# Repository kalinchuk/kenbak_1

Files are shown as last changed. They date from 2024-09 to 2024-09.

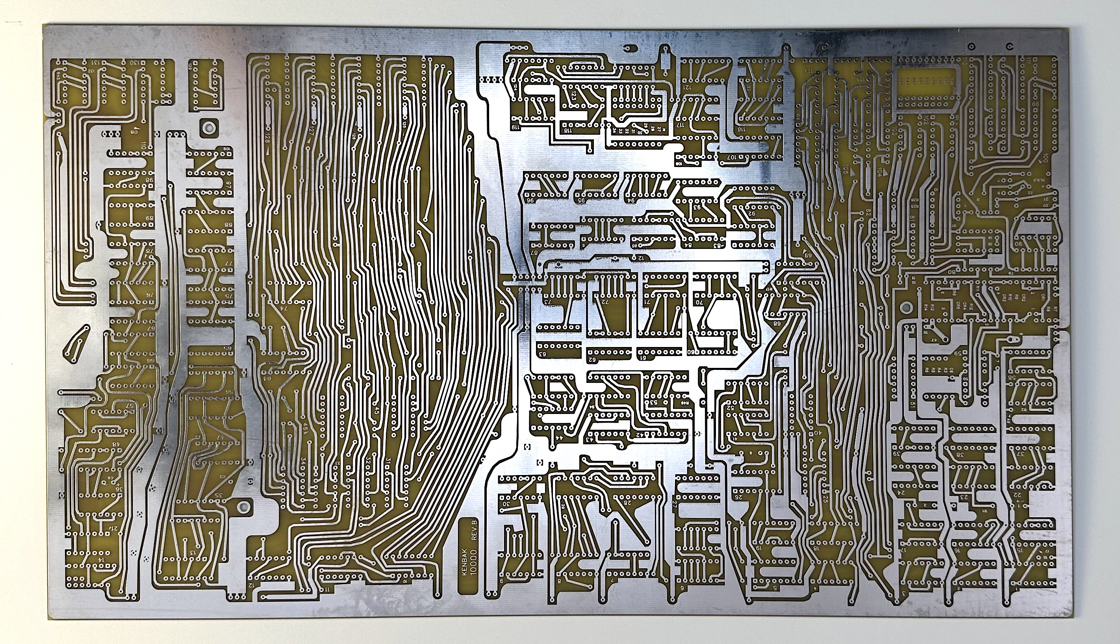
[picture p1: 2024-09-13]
PCB.jpeg

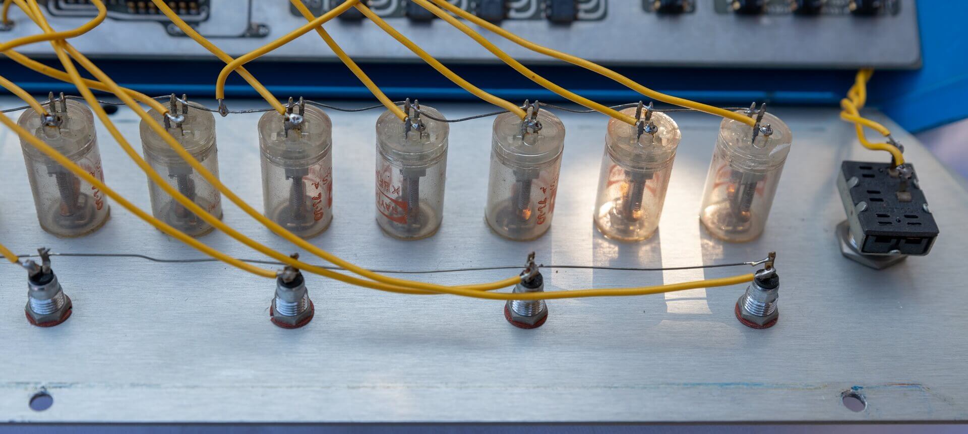
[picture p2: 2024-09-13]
Switches.jpg

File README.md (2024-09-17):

# Kenbak-1 Reproduction

This repository contains schematics, PCBs, instructions and parts lists for the Kenbak-1 reproduction build which can be found at [https://www.youtube.com/watch?v=ffsnZ321Xv4](https://www.youtube.com/watch?v=ffsnZ321Xv4). Be sure to check out [www.kenbak.com](https://www.kenbak.com) for much more details on the Kenbak-1 and its operation. [www.kenbakkit.com](http://www.kenbakkit.com/) also has a lot of resources pertaining to building the reproduction Kenbak-1.

Kenbak-1 Computer

## Resources

You will find the parts list, parts layout, literature (i.e. Theory of Operation), etc. in the tree of this repo.

The parts list and placement can be found [here](Literature/KENBAK-Parts%20Placement%20Guide-Release1.pdf).

Other construction details can be found [here](Literature/KENBAK-Stockly%20Electronics%20Construction%20Manual-Release1.pdf).

## Main PCB

The original Kenbak-1 PCBs are pretty much non-existent. Therefore, if one has the desire to build a Kenbak-1 computer, they need to use a reproduction PCB. I believe it was Thomas Jones who created a reproduction PCB for the Kenbak-1. I used his copper layers to create the Gerber file (included in this repo). I then got the PCBs fabricated and made them available for sale at [www.kalinchuk.com](https://www.kalinchuk.com/product-page/kenbak-1-reproduction-pcb) for anyone wanting to build their own Kenbak-1 computer.

Kenbak-1 PCB

Kenbak-1 Assembled PCB

## Power Supply

The power supply used in the videos and included with the kit: https://www.digikey.com/en/products/detail/integrated-power-designs/1010417CHCO/12757784

## Case

The reproduction Kenbak-1 case was designed by Chris Davis and was based on the original case by Bud Industries. You can find more details on the construction of it at [https://www.pcbway.com/project/shareproject/KENBAK_1_Case_652ebb23.html](https://www.pcbway.com/project/shareproject/KENBAK_1_Case_652ebb23.html).

Kenbak-1 Case

Kenbak-1 Case

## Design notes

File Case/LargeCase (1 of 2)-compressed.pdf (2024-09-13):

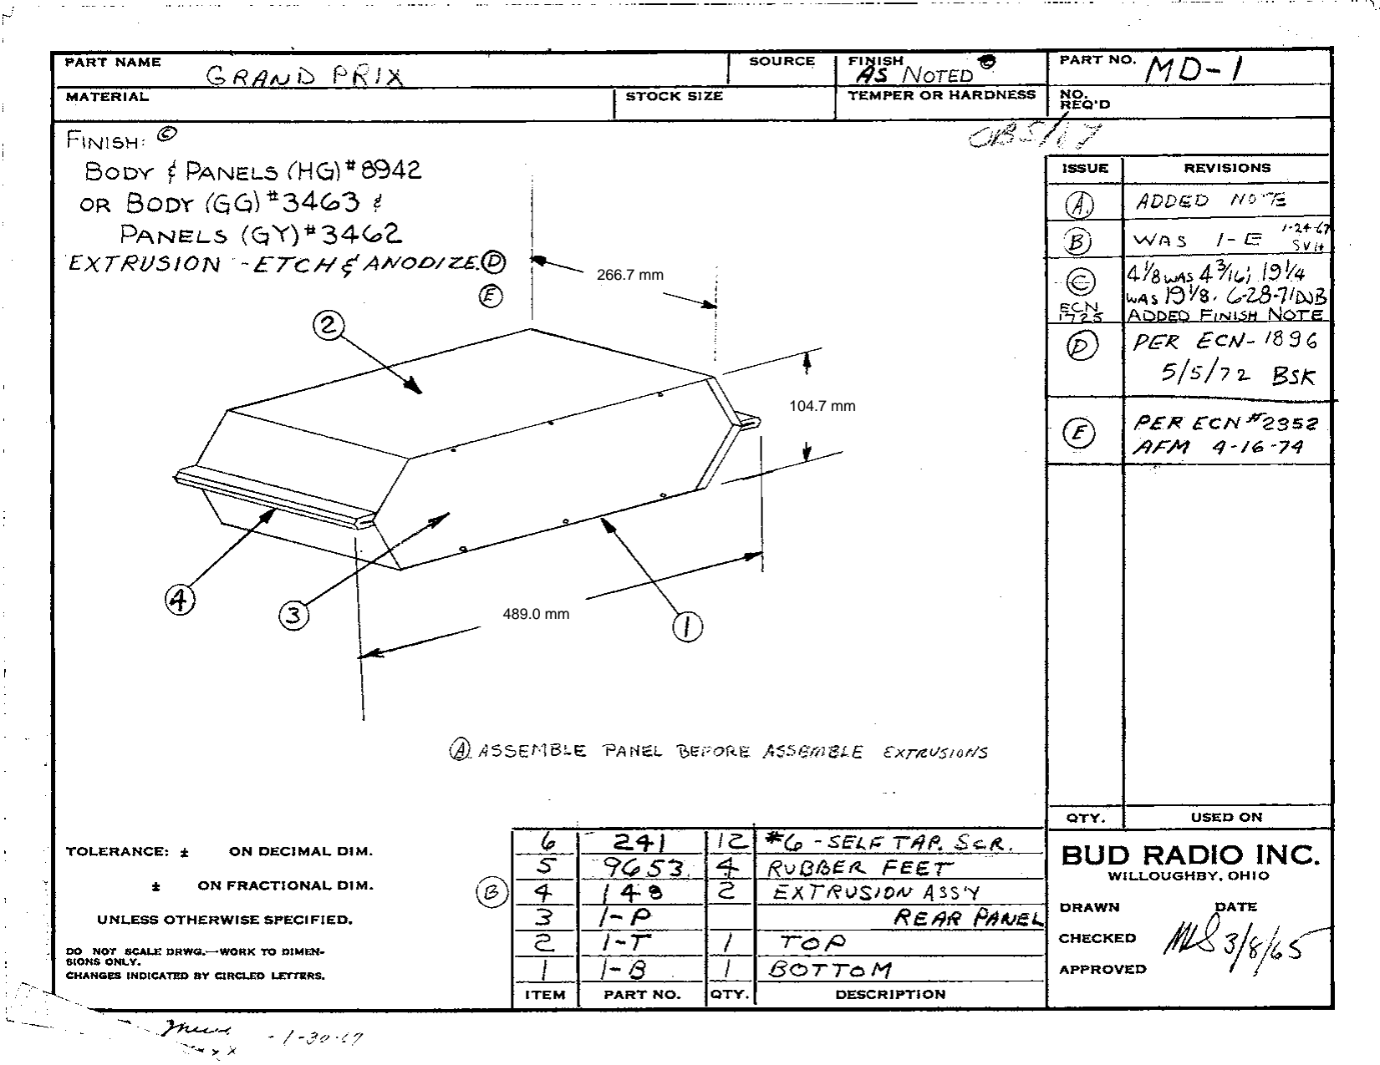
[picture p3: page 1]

266.7 mm

104.7 mm

489.0 mm

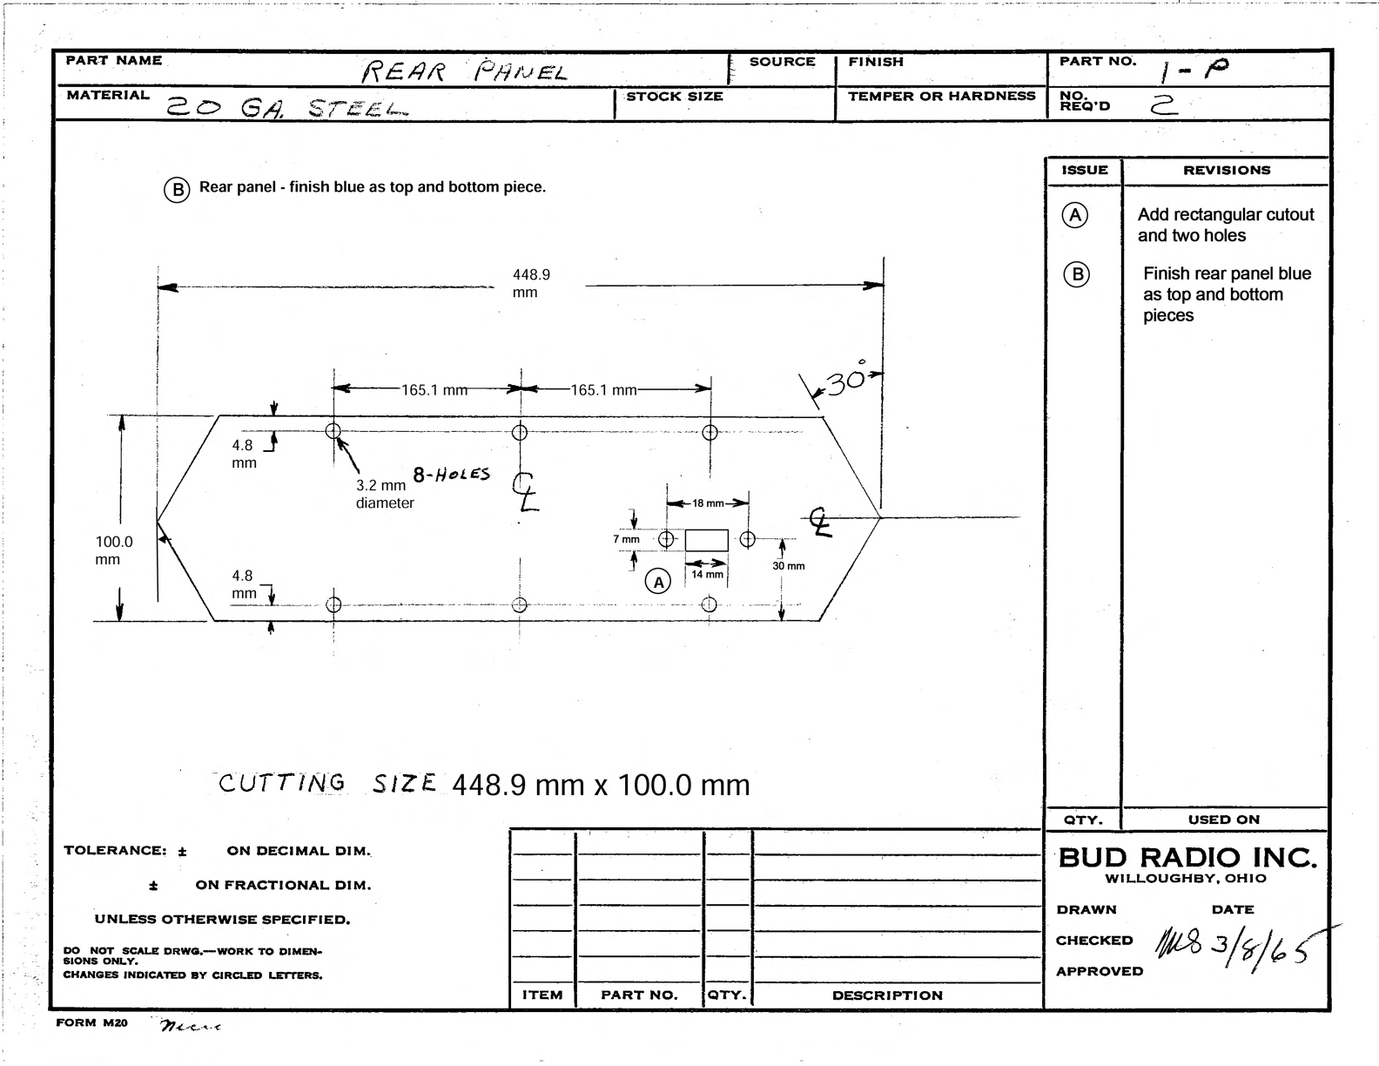
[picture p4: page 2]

## Top and Bottom - 2 pieces

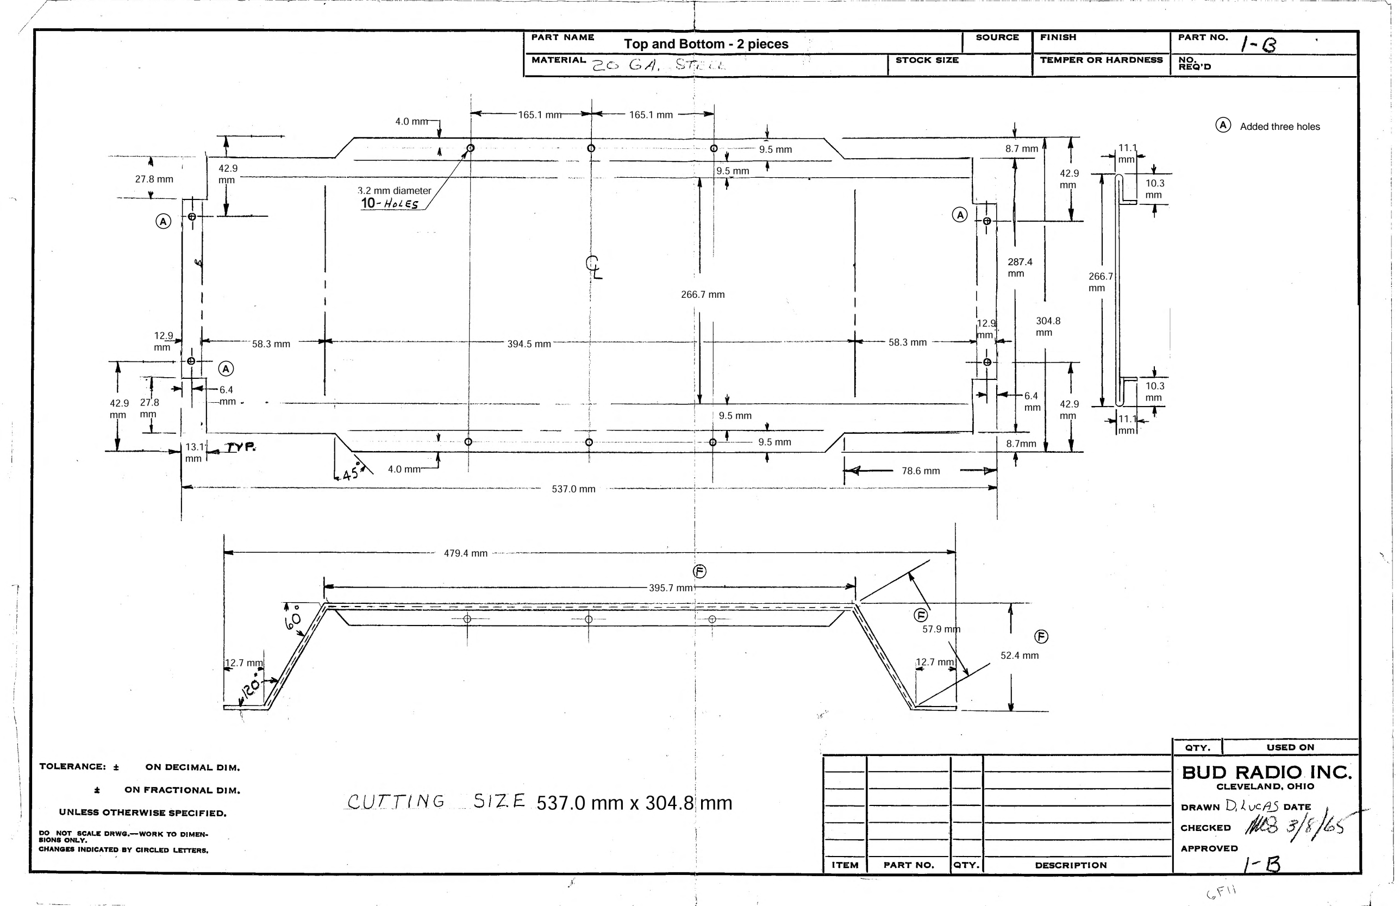
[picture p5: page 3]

A

A

A

A Added three holes

287.4
mm

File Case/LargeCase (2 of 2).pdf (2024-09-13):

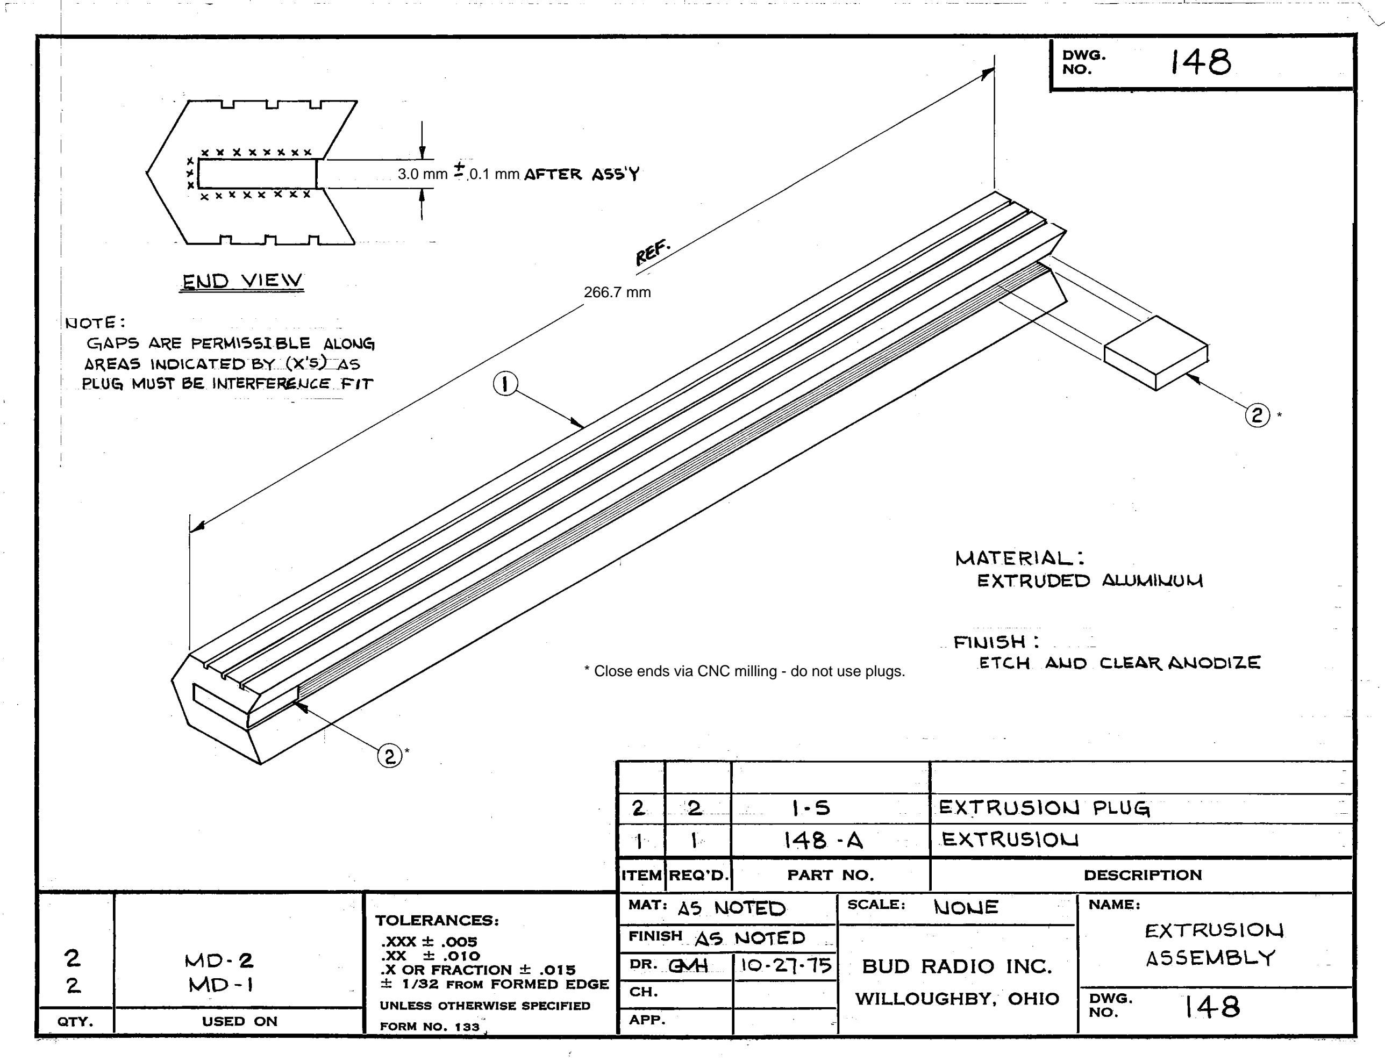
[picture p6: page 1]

3.0 mm 0.1 mm

266.7 mm

## M3 hex

* Close ends via CNC milling - do not use plugs.

*

*

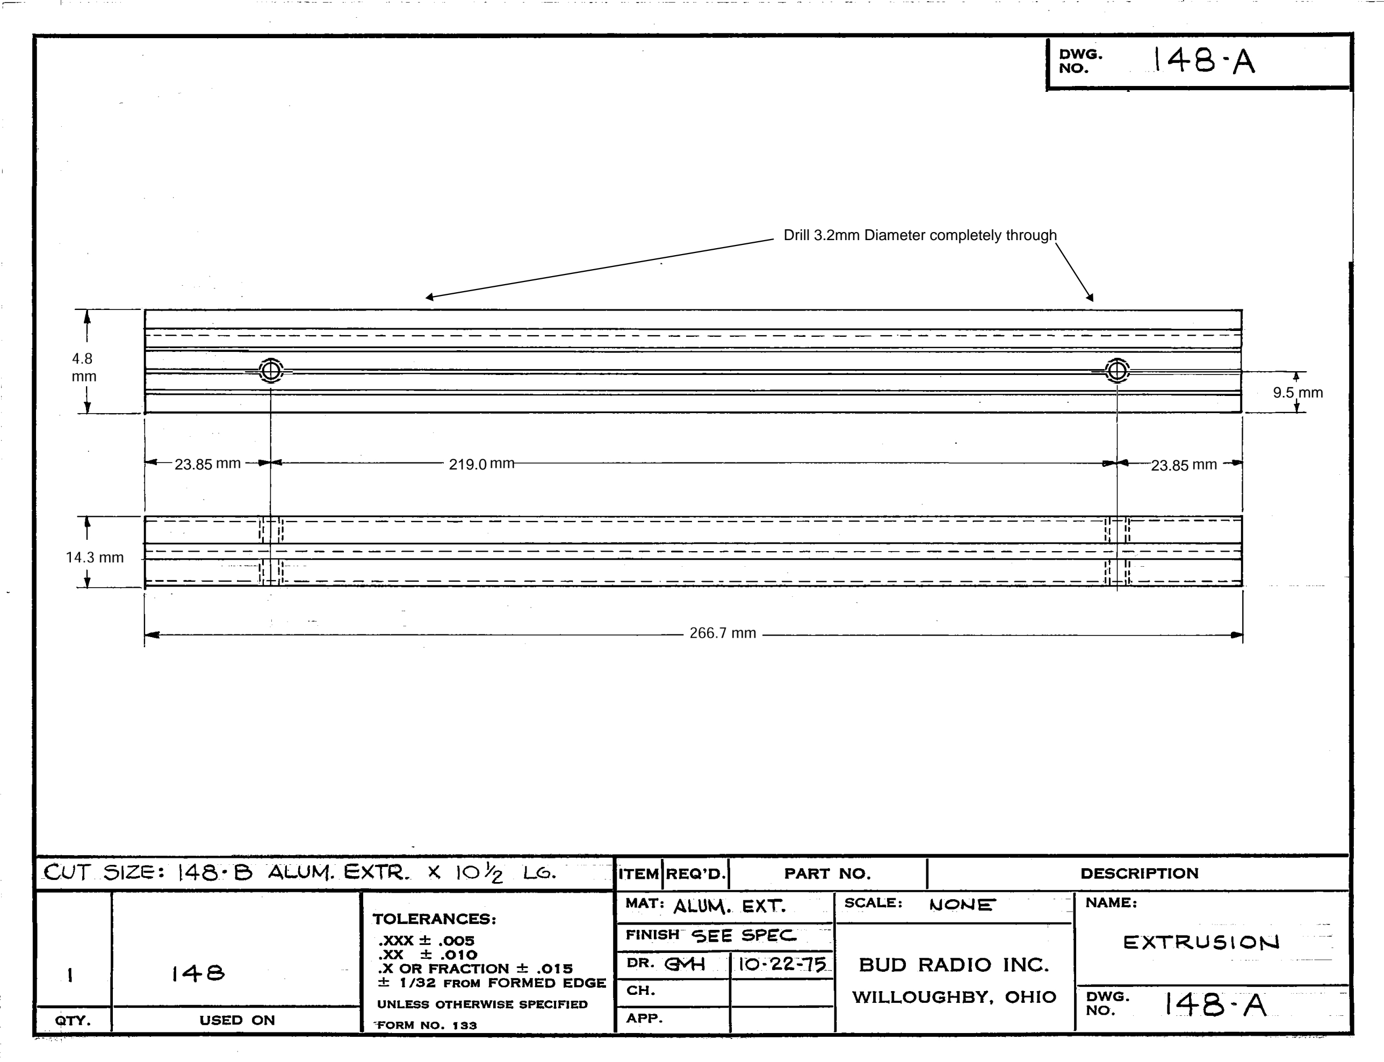
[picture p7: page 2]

Drill 3.2mm Diameter completely through

9.5 mm

23.85 | 219.0 | 23.85

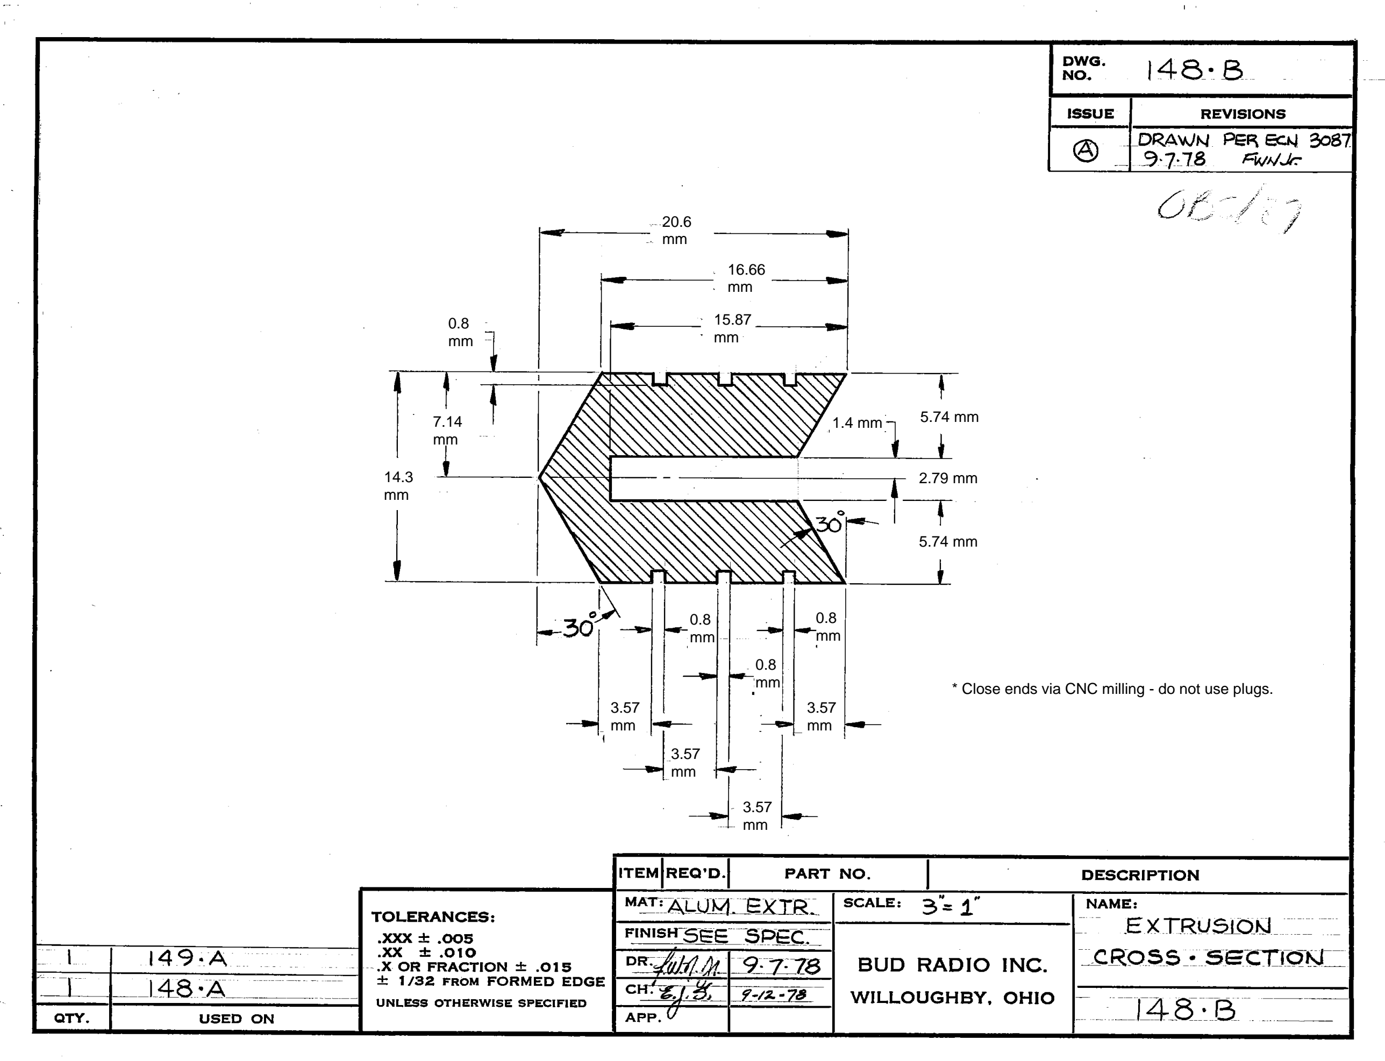
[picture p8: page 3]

14.3
mm

7.14
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
3.57
mm
3.57
mm

3.57
mm

3.57
mm

20.6
mm
16.66
mm

15.87
mm

5.74 mm

5.74 mm

2.79 mm

1.4 mm

* Close ends via CNC milling - do not use plugs.

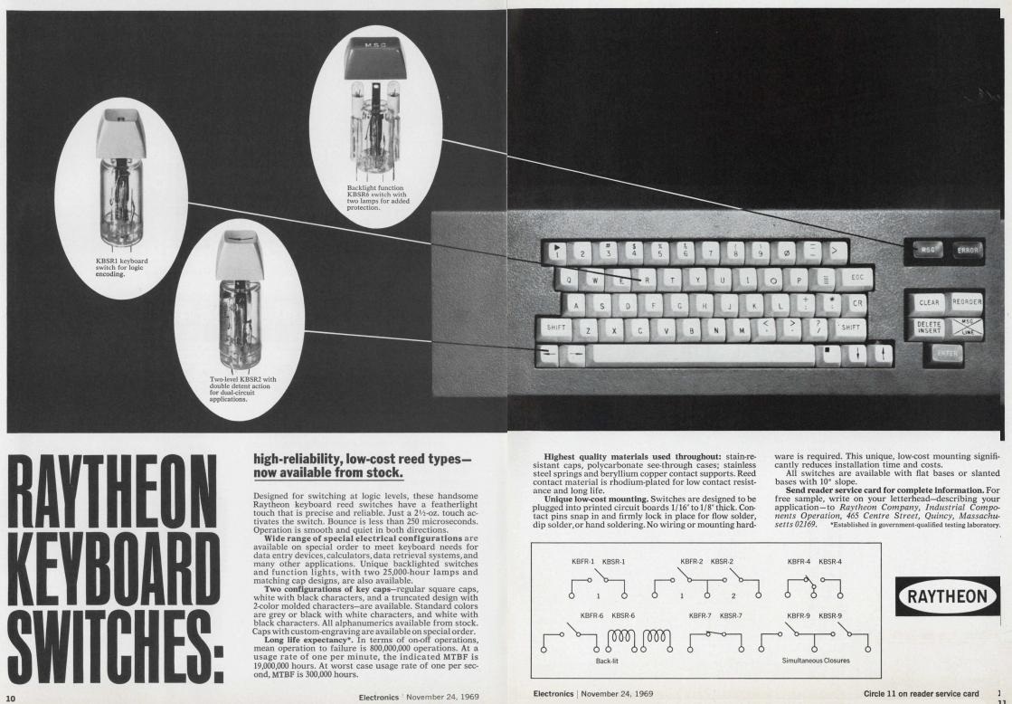
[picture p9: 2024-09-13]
raytheonkeyswitches.png

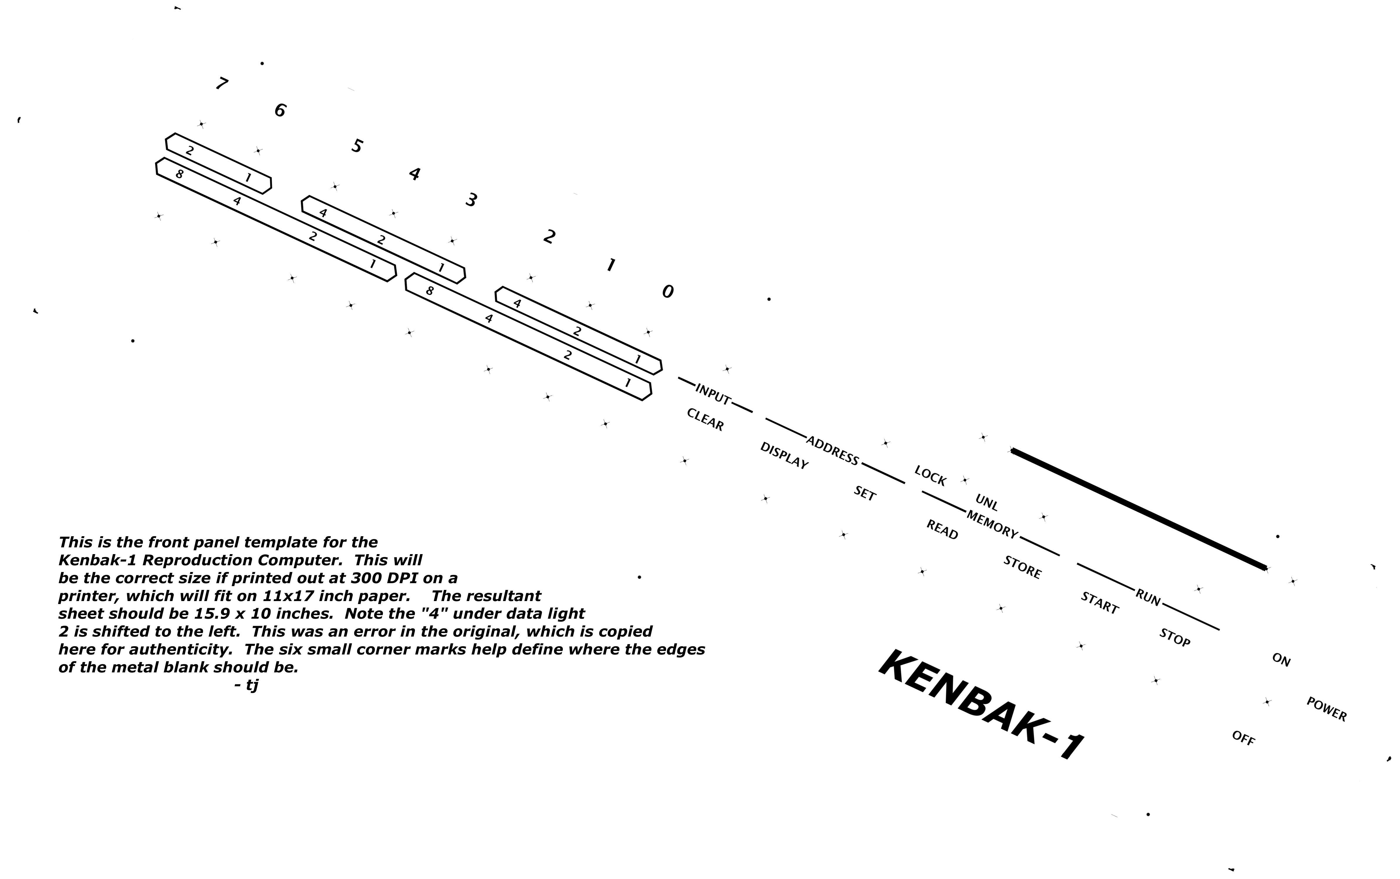
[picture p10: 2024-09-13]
Case/frontpaneltemplate.gif

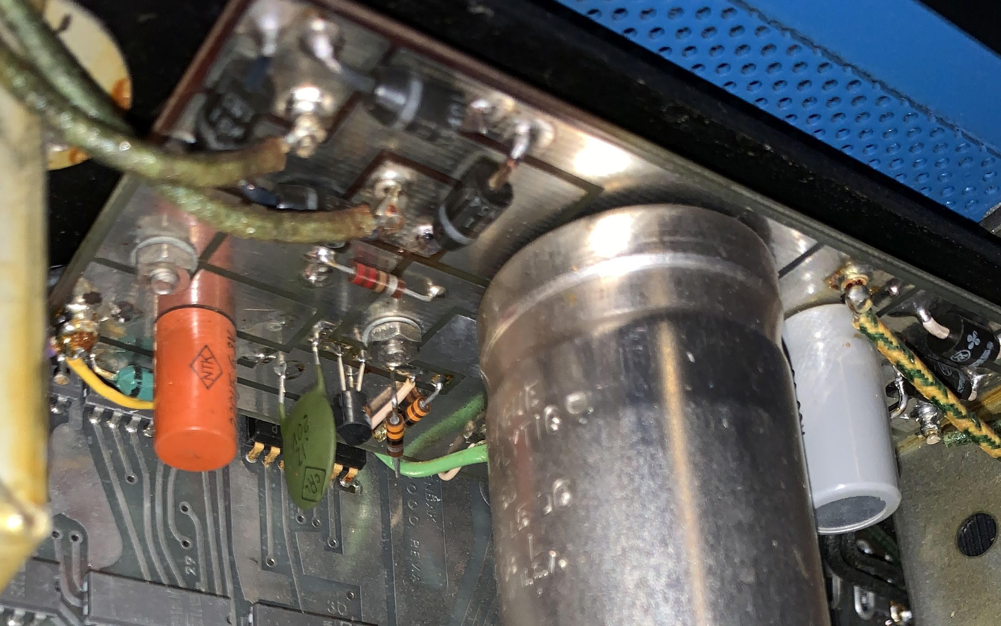
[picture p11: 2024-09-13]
Original Power Supply/powersupply4.jpeg

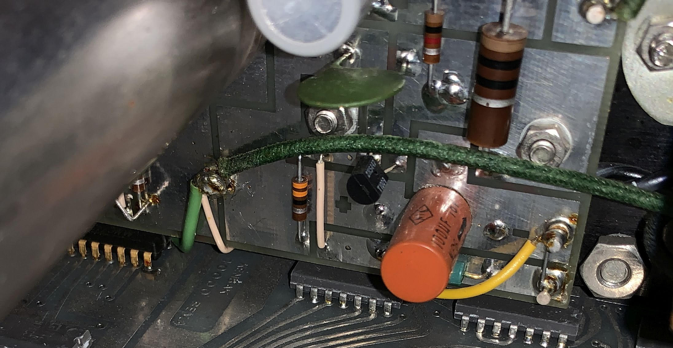
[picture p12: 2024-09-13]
Original Power Supply/powersupply2.jpeg

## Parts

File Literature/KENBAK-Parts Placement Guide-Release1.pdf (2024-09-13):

Kenbak-1 Part Placement – http://www.kenbakkit.com – http://www.stockly.com

ICs:
IC1 | 7410
IC2 | 7495
IC3 | 7400
IC4 | 7420
IC5 | 7400
IC6 | 7495
IC7 | 7400
IC8 | 7404
IC9 | 7430
IC10 7404
IC11 7400
IC12 7400
IC13 7410
IC14 7400
IC15 7400
IC16 7400
IC17 7410
IC18 7410
IC19 7400
IC20 7495
IC21 7420
IC22 7454
IC23 7474
IC24 7400
IC25 7400
IC26 7454
IC27 7454
IC28 7400
IC29 7410
IC30 7400
IC31 7400
IC32 7454
IC33 7400
IC34 7454
IC35 7400
IC36 7410
IC37 7410
IC38 7400
IC39 7486
IC40 7400
IC41 7400
IC42 7495
IC43 7486
IC44 7410
IC45 7400
IC46 7404
IC47 7400
IC48 7400
IC49 7474

IC50 1404A
IC51 7400
IC52 7420
IC53 7474
IC54 7400
IC55 7410
IC56 7410
IC57 7400
IC58 7400
IC59 1404A
IC60 7400
IC61 7410
IC62 7400
IC63 7430
IC64 7400
IC65 7454
IC66 7400
IC67 7430
IC68 7474
IC69 7451
IC70 7400
IC71 7410
IC72 7495
IC73 7495
IC74 7430
IC75 7420
IC76 7400
IC77 7420
IC78 7430
IC79 7410
IC80 7416
IC81 7495
IC82 7495
IC83 7410
IC84 7454
IC85 7400
IC86 7400
IC87 7400
IC88 7430
IC89 7430
IC90 7474
IC91 7400
IC92 7400
IC93 7454
IC94 7420
IC95 7400
IC96 7430
IC97 7430
IC98 7400
IC99 7400

IC100 7486
IC101 7474
IC102 7403
IC103 7403
IC104 7495
IC105 7495
IC106 7454
IC107 7454
IC108 7400
IC109 7420
IC110 7430
IC111 7495
IC112 7495
IC113 7400
IC114 7416
IC115 7416
IC116 7408
IC117 7474
IC118 7400
IC119 7400
IC120 7420
IC121 7410
IC122 7495
IC123 7420
IC124 7400
IC125 7442
IC126 7442
IC127 7442
IC128 7442
IC129 7400
IC130 7474
IC131 7474
IC132 7474

Resistors:
R1 1.0k
R2 1.0k
R3 3.0k
R4 3.0k
R5 3.0k
R6 3.0k
R7 270
R8 220
R9 1.0k
R10 120
R11 1.0k
R12 120
R13 220
R14 270
R15 1k

R16 N/A
R17 1.0k
R18 120
R19 120
R20 1.0k
R21 270
R22 270
R23 N/A
R24 N/A
R25 68
R26 68
R27 1.0k
R28 1.0k
R29 1.0k
R30 1.0k
R31 1.0k
R32 1.0k
R33 1.0k
R34 1.0k
R35 1.0k
R36 1.0k
R37 1.0k
R38 1.0k
R39 1.0k
R40 1.0k
R41 1.0k
R42 1.0k
R43 1.0k
R44 1.0k
R45 1.0k
R46 1.0k
R47 56 2W

Color Codes:
1k Brown-Black-Red
3k Orange-Black-Red
270 Red-Violet-Brown
220 Red-Red-Brown
120 Brown-Red-Brown
68 Blue-Grey-Black
56 Green-Blue-Black

Capacitors:
C1 | 100u100v
| or 0.1u
C2 | 0.1u
C3 | 0.1u
C4 | 100u25v
| or 0.1u
C5 | 0.1u
C6 | 0.1u
C7 | 0.1u
C8 | 0.1u
C9 | 100u25v
or 0.1u
C10 100u100v
C11 0.1u
C12 0.1u
C13 0.1u
C14 100u100v
| or 33u50v
C15 100u100v
or 100u50v
or 0.1u
C16 ~6800p
C17 ~6800p
C18 0.0015u
or 0.001u
C19 0.0015u
or 0.001u
C20 0.1u
C21 0.1u
C22 0.1u

Diodes:
D1 1N914
D2 1N914
D3 1N914
D4 1N914
D5 1N914
D6 1N914
D7 1N914
D8 1N914
D9 1N4733

Transistors:
Q1 2N4401
Q2 MPS3702
Q3 2N4401
Q4 2N4401
Q5 2N4401
Q6 MPS3702
Q7 2N4401
Q8 2N4401

Miscellaneous:
1x1 LAMP +5v
1x1 SWITCH Gnd
1x14 LAMP
1x8 SW1
1x8 SW2
J1 JUMPER WIRE

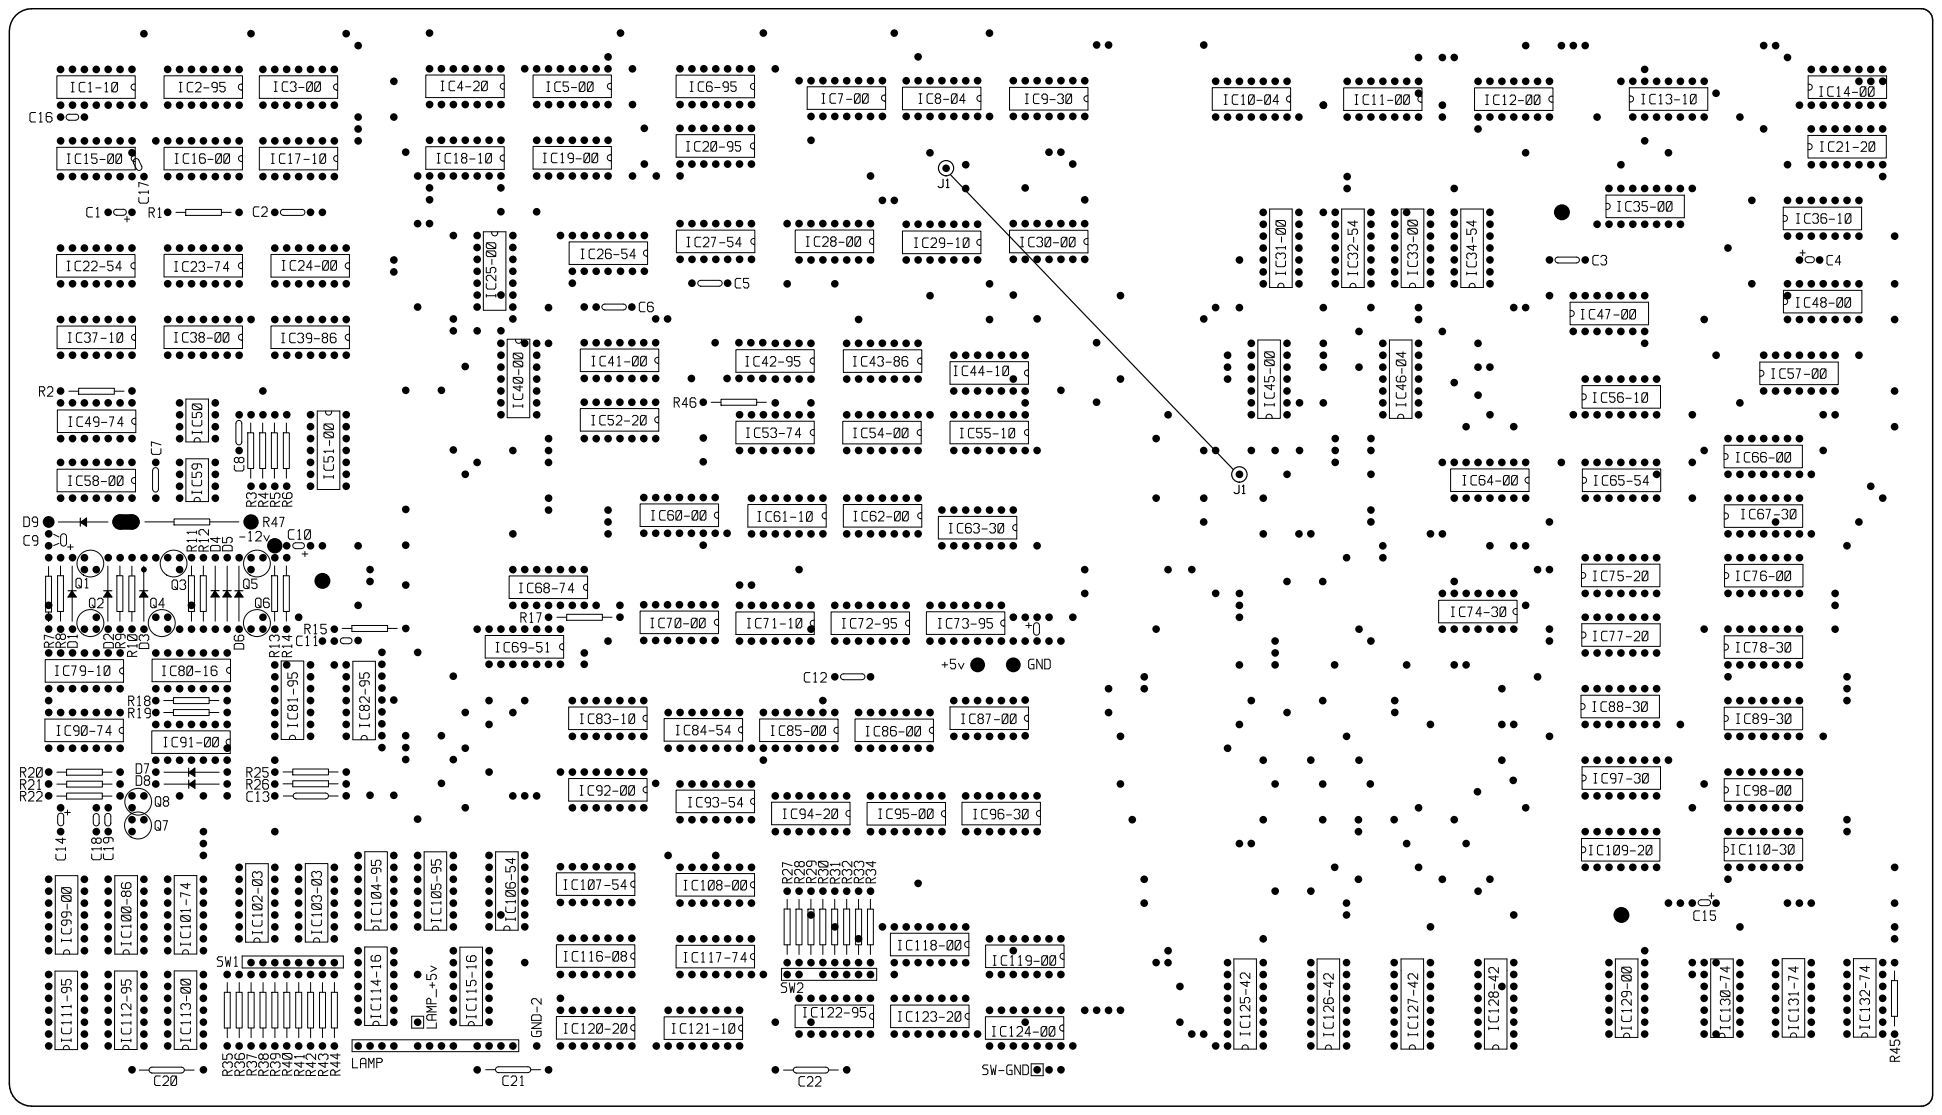
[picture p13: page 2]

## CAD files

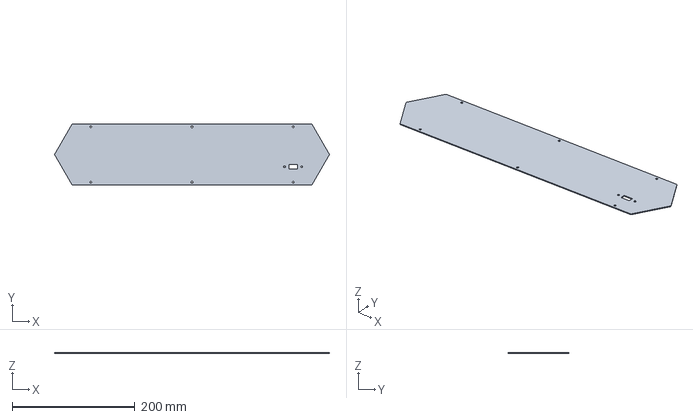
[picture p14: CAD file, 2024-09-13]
Case/RearPanel-Large_Case.iges
448.9 x 100.0 x 1.20 mm

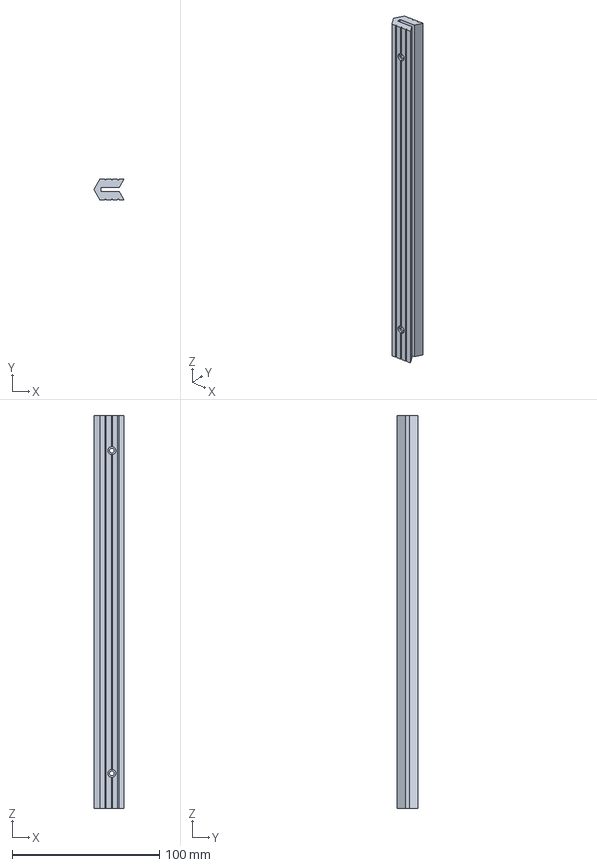
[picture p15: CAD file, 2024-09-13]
Case/SidePiece-Large_Case.iges
20.6 x 14.3 x 266.7 mm

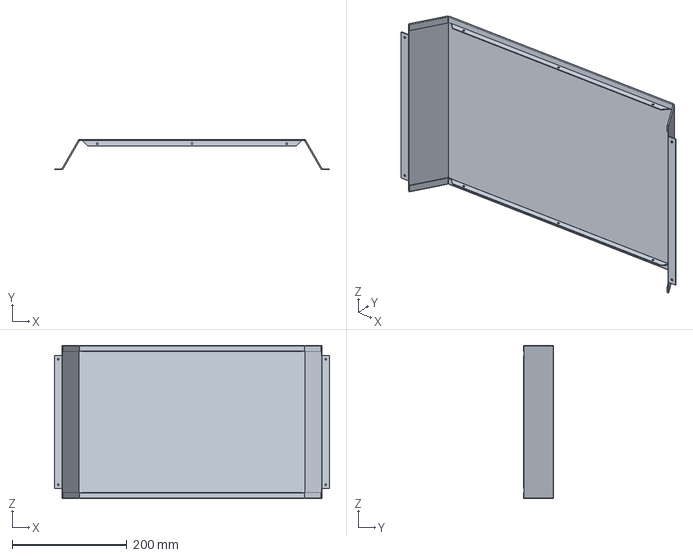
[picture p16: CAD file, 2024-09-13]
Case/CaseTopBottom-Large_Case.iges
479.1 x 52.1 x 266.7 mm

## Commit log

2024-09-13 Adds PCB image
2024-09-13 Adds assembled PCB image
2024-09-13 Adds power supply link
2024-11-30 Front Panel Express files
    Files to fabricate the front and back panels at Front Panel Express. The front panel's holes are sized for modern keyswitches and indicators. The back panel is quite different than the original, with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
    Manufacture at https://shop.frontpanelexpress.com/.
